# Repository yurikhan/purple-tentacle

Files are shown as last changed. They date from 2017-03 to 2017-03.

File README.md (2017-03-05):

# Purple Tentacle Keyboard

A DIY ergonomic mechanical computer keyboard.

## License

[][cc-by-sa4]

This work is licensed under a [Creative Commons Attribution-ShareAlike
4.0 International License][cc-by-sa4].

[badge]: https://i.creativecommons.org/l/by-sa/4.0/88x31.png
[cc-by-sa4]: http://creativecommons.org/licenses/by-sa/4.0/

The TMK Keyboard Firmware is licensed under GPL version 2 or later. Some
of its protocol files are under Modified BSD License.

Third party libraries used in the firmware have their own licenses.

## Documentation

For design documentation and build instructions, see the
[project site][site].

[site]: https://yurikhan.github.io/purple-tentacle/

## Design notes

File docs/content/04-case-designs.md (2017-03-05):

Title: Case designs
Date: 2017-01-27
Summary: The sandwich case.

## Overview

The case consists of four parts,
bottom to top:

<div markdown="1">
<figure>[][bottom]
<figcaption>[Bottom plate][bottom]</figcaption></figure>
<figure>[][spacer]
<figcaption>[Spacer][spacer]</figcaption></figure>
<figure>[][plate]
<figcaption>[Mounting plate][plate]</figcaption></figure>
<figure>[][frame]
<figcaption>[Top frame][frame]</figcaption></figure>
</div>

[bottom]: {filename}/images/04-case-designs/bottom.svg
[spacer]: {filename}/images/04-case-designs/spacer.svg
[plate]: {filename}/images/04-case-designs/plate.svg
[frame]: {filename}/images/04-case-designs/frame.svg

Seven M3 bolts with nuts
hold the parts together.

Palm supports are attached to the bottom plate
with M6 bolts and nuts.
The nuts are held in place
by the hexagonal cutouts in the spacer.

DXF files suitable for laser cutting
are available [from the project repository][dxfs].

[dxfs]: https://github.com/yurikhan/purple-tentacle/case/

## Source files

The remainder of this page
is only important
if you want to modify the physical layout.

This instruction assumes
you have the following software installed:

* LibreCAD

* Python 3

    * Additional packages
      listed in [`requirements.txt`][req].
      You should be able to install them with:

            $ pip3 install --user --requirement requirements.txt

* GNU Make

The preferred source for the case design
is the `master.dxf` file.
It uses blocks to make the design more flexible
and layers to separate case details.

After you modify the master drawing,
run `make all` in the `case` directory.
This will update the individual part DXFs
and images for this instruction.

[req]: https://github.com/yurikhan/purple-tentacle/tools/requirements.txt

## Table of Contents

[TOC]

### Layers

#### 0

The default layer.
Inserts of blocks go here.

#### Bottom, Spacer, Plate, and Frame

Contours that are unique to the named part.

#### Case upper

Contours common to the mounting plate and frame.

#### Case lower

Contours common to the bottom plate and spacer.

#### Case

Common contours of all details.

#### Keycaps

Rectangles for each keycap,
to aid the construction of cutouts in the top frame.

#### Palm supports

Schematics of the palm supports,
to aid in placing the attachment holes.

#### Construction: *

Several layers with auxiliary construction lines
which explain how features are placed.

#### Labels

Sizes, distances, offsets, and rounding radii.

### Blocks

#### Keyswitch cutout

A cutout for one keyswitch.
Change this if you plan to build a Cherry MX-based board.

#### Key

A [keyswitch cutout](#keyswitch-cutout)
and a single 1-unit keycap (19×19 mm).

#### Frame Key

A frame cutout for a single 1-unit [key](#key).

#### Key 1.5

A [keyswitch cutout](#keyswitch-cutout)
and a 1.5-unit keycap,
for the thumb base keys.

#### Frame Key 1.5

A frame cutout for a single [1.5-unit key](#key-1.5).

#### Frame Fgroup

A frame cutout for a horizontal row of four keys.

#### Fgroup

Four [key](#key)s in a horizontal row,
with a [frame cutout](#frame-fgroup),
for function keys.

#### Fkeys

Three [Fgroup](#fgroup)s,
plus two single [key](#key)s on the sides
with corresponding [frame cutout](#frame-key)s.

#### Column

Four [key](#key)s in a vertical column,
grouped so that you could easily adjust column staggering
in the [Hand](#hand) block.

#### Columns

Eight [column](#column)s
arranged according to column stagger.

If you ever need to adjust the column staggering pattern,
this is the place to do it.
It will be mirrored symmetrically.

#### Diamond

Four [key](#key)s in a diamond shape,
for navigation clusters.

#### Thumb cluster

Three 1-unit [key](#key)s
and a single [1.5-unit key](#key-1.5)
with a frame cutout,
for thumb clusters.

#### Hand

Combines the [columns](#columns),
a navigation cluster [diamond](#diamond),
and a [thumb cluster](#thumb-cluster).

#### LED

A 3 mm hole for a single LED.

If you use an opaque material for the top frame,
move the hole from the *Plate* layer
to the *Case upper* layer.

#### LEDs

Three [LED](#led) blocks in a vertical column.

The default LED spacing
is one unit (19 mm).

#### Case screw

A hole for an M3 bolt through all layers.

#### Palm support

* *Palm supports* layer:
  A schematic of the palm support.
* *Bottom* layer:
  Two holes for M6 bolts,
  coinciding with the mounting holes
  on the palm support base.
* *Spacer* layer:
  Cutouts for two hexagonal M6 nuts.

#### Main drawing

Combines the major blocks into a whole:

* [Function key bar](#fkeys)
* Two symmetrical [hand](#hand) blocks,
  each rotated about the origin
  by half the split angle
* [LEDs](#leds)
* [Case screw](#case-screw) holes
* [Palm rest](#palm-rest) attachment holes

This is also where all the manually constructed contours go:

* Frame cutout for the main block
* Exterior boundary
* Spacer cutout

Unfortunately, it’s not easy to automate these.
If you change the matrix,
you will have to re-construct them.
Open a copy of the original drawing alongside
and follow the hints in the *Construction* layers.

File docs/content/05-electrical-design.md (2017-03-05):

Title: Electrical design
Date: 2017-02-26
Summary: The wiring scheme.

## Overview

For reading convenience,
the schematic diagram is presented in three parts,
one part for each half of the matrix
and one part showing controller connection.

<div markdown="1">
<figure>[][left]
<figcaption>[Left half][left]</figcaption></figure>
<figure>[][right]
<figcaption>[Right half][right]</figcaption></figure>
<figure>[][schematic]
<figcaption>[Controller connection][schematic]</figcaption></figure>
</div>

[left]: {filename}images/05-electrical-design/left.sch.svg
[right]: {filename}images/05-electrical-design/right.sch.svg
[schematic]: {filename}images/05-electrical-design/schematic.sch.svg

**Note** that the column wires of opposite halves connect,
while the row wires do not.

## Source

These schematics are drawn in KiCad EDA.
The source project is in the `schematic` subdirectory.

The images above
are exported using the <kbd><kbd>File</kbd> | <kbd>Plot</kbd></kbd> command,
SVG format,
color mode,
no border and title block,
<kbd>Plot Current Page</kbd> individually for each page.
Afterwards, the SVG images are cropped using Inkscape.
A `Makefile` is provided.

## Concept

The keyswitches are arranged in a matrix
with 12 semi-rows
by 8 columns.
This allows a maximum of 96 keys
using 20 I/O pins.
(The theoretical maximum for 20 pins is
10×10 = 100 keys,
but 12×8 is a bit nicer to work with.
19 pins are insufficient
because they only allow 10×9 = 90 keys.)

The correspondence between keys and matrix cells
is pretty straightforward.
Note that function keys use the innermost columns.
Also note that the navigation and thumb clusters
are wired in a pseudo-row labeled AZ,
with three bottommost keys
arbitrarily assigned to the three outer columns.

An anti-ghosting diode
is placed in series with each keyswitch.
(See the [Rollover, blocking and ghosting][ghosting] article
on the Deskthority wiki
for details.)

[ghosting]: https://deskthority.net/wiki/Rollover,_blocking_and_ghosting

Keyswitches are wired for *active-low* logic.
That is, in order to read a semi-row,
the firmware pulls the corresponding semi-row pin to the ground,
activates the controller’s internal pull-up resistors
to drive inactive columns high,
and senses which column pins went low
as a result of keys being held down.
Thus, diodes have to be directed
towards semi-row wires.

(Active-high logic
would require pulling inactive columns down,
and the Atmega32U4 does not have internal pull-down resistors.
Without pull-downs,
inactive columns would become indeterminate.)

The eight column wires are connected
to the eight pins on the top edge of the Arduino Micro.
The twelve semi-row wires are connected
to pins on the bottom edge.
This leaves three pins
for the status LEDs.

The `RXLED` (`PB0`) pin is left unused.
In experiments,
it wouldn’t keep its assigned state.

Each LED is connected to a PWM-enabled pin
so that the firmware could control their brightness.
(This ability is currently unused;
the firmware implements its own PWM.)

The `PC7` pin,
also known as pin 13 in Arduino Micro,
normally drives the on-board LED.
The controller bootloader blinks this LED
while it’s working.
Wiring an externally visible LED to this pin
makes it possible to observe this blinking
when plugging the keyboard in
before the actual firmware kicks in.

LEDs are wired for *active-high* logic.
That is, the firmware pulls the LED anode pin to +5 V,
allowing the current
to flow through the LED into the ground.
(This simplifies reasoning about the LED state
in the firmware.)

A current limiting resistor is wired
in series with each LED.
See the [Limiting resistors][resistors] section
in the Bill of Materials
for the resistor value calculation formula.

[resistors]: {filename}03-materials.md#limiting-resistors

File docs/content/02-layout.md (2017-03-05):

Title: Layout
Date: 2016-12-10T14:00Z
Summary: Column-staggered, fixed split tenkeyless layout with thumb arcs.

Here is the physical layout of Purple Tentacle,
with various key groups highlighted.
The default keymap is shown;
you will be able to customize it.

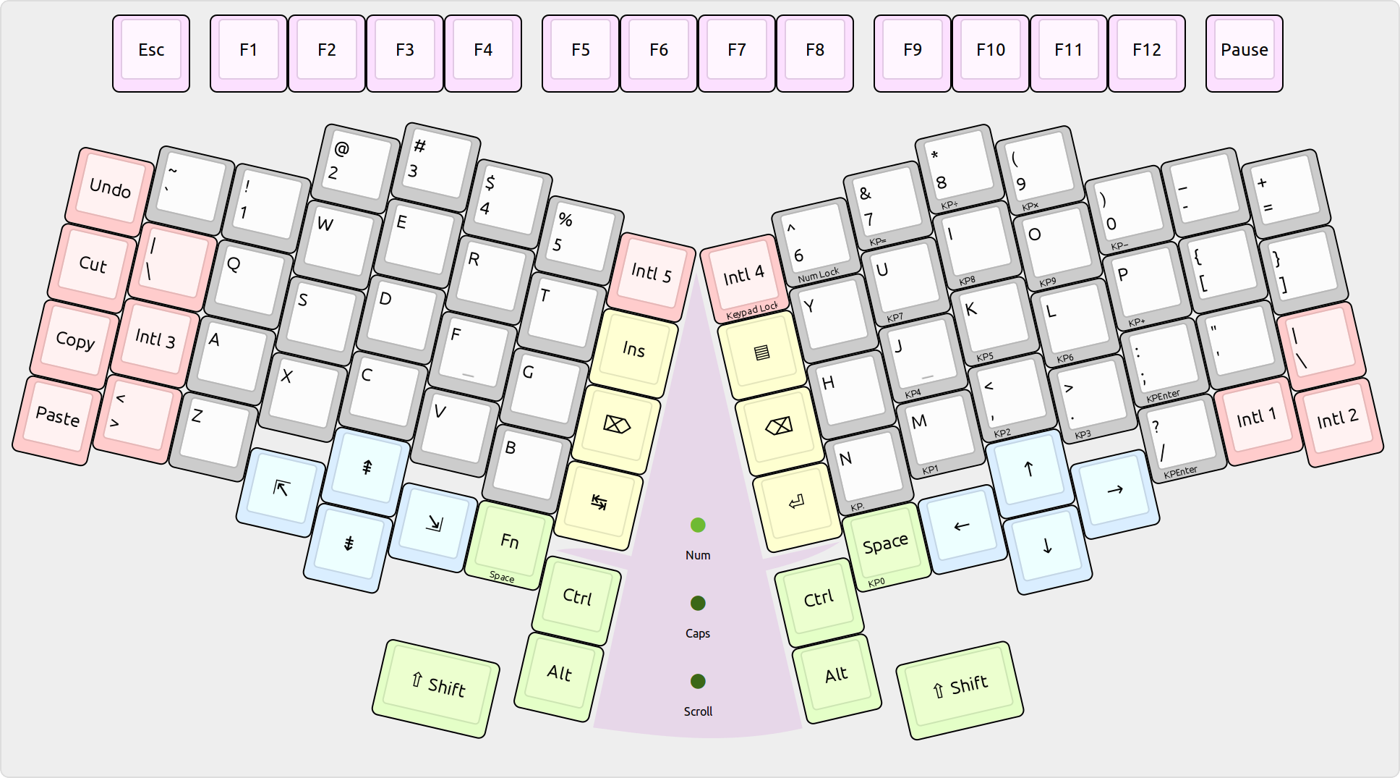
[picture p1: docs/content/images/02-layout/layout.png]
[][source]

[source]: http://www.keyboard-layout-editor.com/#/gists/0eb51054919d0ed51396cbd71c97c7d0

(Forking note:
the Corresponding Source for this image
is available [online][source].)

The main area is split into two halves,
with a fixed 26° angle between them.
(This provides the ergonomic advantages
of a split keyboard
while keeping the case design simple.)

Keys in the main area are arranged in straight columns,
which are staggered in accordance with finger lengths.

There are eight columns in each half;
the home position spans four columns in the middle.
Two additional outside columns are provided for the pinky,
and two inside columns for the index finger.
(This is in contrast
to the conventional non-split layout,
which has only two inside columns,
one outside column on the left
and three to four outside columns on the right,
overworking the right pinky.)

The default keymap
moves the most frequently used editing keys —
<kbd>Backspace</kbd>,
<kbd>Enter</kbd>,
<kbd>Tab</kbd>,
and <kbd>Delete</kbd>
(highlighted in yellow) — to the inside columns,
and duplicates one punctuation key
(US <kbd>\|</kbd>, or UK <kbd>#~</kbd>)
on the left hand.

This leaves several spare keys for user experimentation
(highlighted in red).
The default keymap assigns them
in a way that tries to accommodate most national layouts
out of the box.
However, if you create a keymap
that is substantially better
for a particular language,
please [send a pull request][pull]!

[pull]: https://github.com/yurikhan/purple-tentacle/pulls

Apart for the main area,
the layout includes:

* Function keys on the top,
  in groups of four
  (highlighted in purple).
  This grouping aids in finding them by touch.
* Two diamond-shape navigation clusters,
  positioned in the index–middle–ring finger columns
  and accessible without moving the wrist
  (highlighted in blue).
* Three keys for each thumb
  and two keys to be pressed with the base of the thumbs
  (highlighted in green).
  Arranging modifiers as shown above
  makes it possible to press two modifiers
  simultaneously with one thumb
  while leaving the other fingers in their home position.

The triangular shape in the middle,
highlighted in purple,
with the green status LEDs,
resembles a character from Day of the Tentacle,
a 1993 video game.
This is what the keyboard is named after.
(@Lucasfilm:
If you feel this infringes your trademark,
please [file an issue][issues].)

[issues]: https://github.com/yurikhan/purple-tentacle/issues

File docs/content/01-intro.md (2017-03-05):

Title: Introduction
Date: 2016-12-10T09:33Z
Summary: Purple Tentacle is a simple ergonomic desktop computer keyboard.

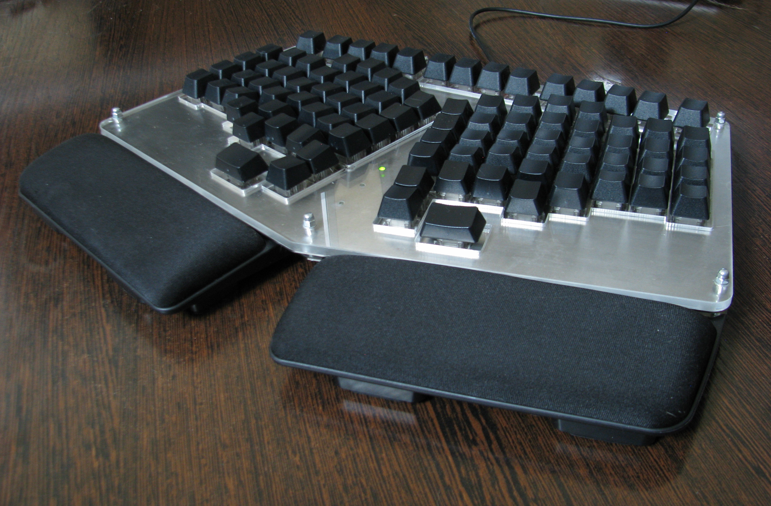
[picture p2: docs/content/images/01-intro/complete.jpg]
[][photo]

[photo]: {filename}/images/01-intro/complete.jpg

In a nutshell, Purple Tentacle is a
DIY
flat
one-piece
fixed split
ergonomic
mechanical
computer keyboard
for use with a desktop computer.

It pursues two goals:

* **Be simple to design and build.**
  You need to
  have access to a laser cutting facility
  and be able to solder,
  but that is pretty much it.

* **Be reasonably comfortable to use.**
  The computer keyboard as we know it today
  has evolved from a typewriter keyboard.
  Features were added
  while preserving backward compatibility.
  Some of the constraints underlying the designs
  are no longer relevant.

Minimalism is explicitly *not* a goal.
This is a desktop computer keyboard.
It’s not sacrificing functionality
in an attempt to make it easier
to carry around with you all the time.

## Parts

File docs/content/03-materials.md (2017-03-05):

Title: Bill of materials
Date: 2016-12-10T16:00Z
Summary: Parts you need in order to build a Purple Tentacle.

Here is the list
of parts and materials comprising a Purple Tentacle.
All costs are approximate.
Shipping is not included
as it will vary according to your location.

Proprietary parts are marked with a © symbol.
They are designed and produced
by the [Matias Corporation][matias].
In Europe, check [The Keyboard Company][keyboardco].

[matias]: http://matias.ca/
[keyboardco]: http://www.keyboardco.com/

|Part |Qty|©|Cost≈  |
|---|--:|-|---:|
|[Key switch](#key-switches) | 94|©|[^1]$25|
|[Keycaps](#keycaps) | 94|©|[^2]$50|
|[Palm supports](#palm-supports) (optional)|  1|©| $50|
|[Controller board](#controller-board) |  1| | $20|
|[USB cable](#cable) |  1| | $5|
|[Anti-ghosting diode](#diodes) | 94| | $1|
|[Status LED](#status-leds) |  3| | $1|
|[Limiting resistor](#limiting-resistors)  |  3| | $1|
|[Mounting plate](#mounting-plate) |  1| | $9|
|[Bottom plate](#bottom-plate) |  1| | $6|
|[Spacer](#spacer) |  1| | $15|
|[Top frame](#top-frame) (optional) |  1| | $10|
|[Wire](#wire) |12 m| | $1|
|[M3×… bolt](#m3-bolts-and-nuts) |  7| | $1|
|[M3 washer](#m3-bolts-and-nuts) | 14| | $1|
|[M3 acorn nut](#m3-bolts-and-nuts) |  7| | $1|
|[M6×10 bolt](#m6-bolts-and-nuts) |  4| | $1|
|[M6 washer](#m6-bolts-and-nuts) |  4| | $1|
|[M6 hexagonal nut](#m6-bolts-and-nuts) |  4| | $1|
|[Self-adhesive rubber feet](#rubber-feet) |2–5| | $7|
|**Subtotal (no palm supports)** | | |**≈$150**|
|**Subtotal** | | |**≈$200**|

## Key switches

Purple Tentacle is designed around Matias key switches.
A Cherry MX-based variant is possible
but many adjustments will be required
(different cutout size,
different plate thickness,
possibly different frame thickness).

Matias switches come in three variants:

* Quiet Click (PG155B01 or KS101Q)
* Click (PG155B02 or KS101)
* Quiet Linear (KS102Q)

They are sold in boxes of 200,
at $50 a box.

[^1]: Assuming you build two units,
    or split a box with a friend.

If unsure, choose Quiet Click.

## Keycaps

Matias keycaps are available in black or white;
blank or labeled.
They are made of ABS plastic,
have matte cylindrical surface,
and differ by row.

When choosing,
keep in mind the following considerations:

* The blank sets offered by the Matias Corporation directly
  have more keycaps than any of the labeled sets.
* The blank sets sold by The Keyboard Company,
  on the other hand,
  might not.
  Read the description carefully.
* Labeled sets are tailored
  to the conventional keyboard layout.
  You will be able to put *a* cap on each key,
  but not all labels will make sense.
  For example,
  no set offers a single-unit <kbd>Enter</kbd> keycap.

[Signature Plastics][sp] offers a limited selection
of keycaps with Alps mounts;
these are blank only,
more expensive,
and in various colors and profiles.

[sp]: http://pimpmykeyboard.com/

There is no default for the keycaps;
you have to make this choice.

[^2]: Assuming a Matias keycap set,
    with no Signature Plastics additions.

## Palm supports

Purple Tentacle uses palm supports
designed for the Matias Ergo Pro keyboard.
These come in five colors:
White, Black, Red, Navy Blue, and Astronaut Blue.
They are gel pads covered with silk,
attached to a plastic/steel base.

Whether to use palm supports
is a personal choice,
dependent on your typing habits.

If you do use the palm supports,
they will accumulate lint from your palms.
Once in a while,
detach them
and hand-wash with soap.
Do not put in a washing machine!
Dishwasher compatibility not tested.

## Controller board

For the controller,
choose an Atmel ATmega32u4-based breakout board
which exposes at least 23 I/O pins,
is wired for 5 V,
and is sufficiently small (≈50×20 mm or so).
Possibilities include
(but are not necessarily limited to):

* [Arduino Micro][arduino] or clone
* [Adafruit Atmega32u4 Breakout Board][adafruit]
* [Pololu A-Star 32U4 Mini][astar]
* [PJRC Teensy 2.0][teensy]

[arduino]: https://www.arduino.cc/en/Main/arduinoBoardMicro
[adafruit]: https://www.adafruit.com/products/296
[astar]: https://www.pololu.com/product/3102
[teensy]: https://www.pjrc.com/teensy/index.html

These boards do *not* expose enough pins:

* Pololu A-Star 32U4 Micro (18 pins)
* SparkFun Pro Micro (18 pins)

This instruction assumes Arduino Micro.
For other boards,
minor adjustments to wiring
and/or firmware may be needed.

Note that some boards
will not advertise their total pin number.
For example,
Arduino Micro advertises 20.
For best results,
check the schematic
and count I/O pins
which have no other components attached.

If the board has a pin
that only drives a general-purpose LED,
count it also;
use it for one of the keyboard status LEDs.
(This way you get useful feedback
when the bootloader flashes this LED.)
Avoid pins that drive fixed-purpose LEDs
such as RXLED and TXLED.

Given a choice, prefer boards
that come *without* solderless breadboard pins attached —
they won’t fit in the keyboard case
and you’ll have to desolder them.

## Cable

Choose a cable so
that one end fits the controller board
(either mini or micro USB B male connector)
and the other end has a standard USB A male connector.
Choose a length that fits your working environment.
Avoid ferrite rings
and L-shaped connectors
as they will be a hassle to fit in the keyboard case.

## Diodes

To prevent ghosting,
a diode is installed
in series with each key switch.

This instruction assumes 1N4148 diodes.

## Status LEDs

For status indicators
(Num Lock, Caps Lock, Scroll Lock),
choose LEDs that will
fit in 8 mm space
and have forward voltage of 3 V or less.
Prefer diffused ones.
Choose through-hole mount,
not surface mount.

This instruction assumes ⌀3 mm green LEDs,
forward voltage 1.8–2 V,
maximum current 20 mA.

## Limiting resistors

Calculate the minimum limiting resistor value as
<var>R</var><sub>min</sub> =
(<var>V</var><sub>cc</sub>
− <var>V</var><sub>f</sub>)
/ <var>I</var><sub>max</sub>,
where
<var>V</var><sub>cc</sub> = 5 V,
<var>V</var><sub>f</sub> is the LED forward voltage,
and <var>I</var><sub>max</sub> is the LED maximum current,
and use an actual value above that
in order to keep the current through LEDs within specifications.

For best results,
try resistors of several values
and choose the one that yields the most comfortable LED brightness.
Your goal is to make the LED noticeable
but not painful to look at.
Be sure to test
both in bright daylight
and in dim lighting.

For example,
for the LEDs specified above
the formula gives a minimum resistance of 150 Ω,
but a 1 kΩ value gives a more pleasant brightness.

## Mounting plate

Matias switches are mounted on a plate 1 mm thick.
Ask your laser cutting facility
what materials they carry.

If in doubt,
choose stainless steel.
(If you make a Purple Tentacle
with a plate made of a different material,
please [share your experience][materials]!)

[materials]: https://github.com/yurikhan/purple-tentacle/issues/1

## Bottom plate

The bottom plate covers the electronics from below.
If you choose to use palm supports,
the bottom plate is what they attach to.

This instruction assumes 1 mm stainless steel,
same as the mounting plate.

## Spacer

The spacer is the layer of the case
between the bottom plate and the mounting plate.
It provides outer walls
for the internal cavity
that houses the electronics.

This layer must be at least 9 mm thick.
When key switches are inserted into the mounting plate,
their pin ends will go 8 mm below the plate level,
and you will need a little space
so that the bottom plate does not touch them.

Ask your laser cutter facility
what materials they carry
and what they work with.
If they don’t have anything suitable,
ask what size the raws need to be.

The choice is purely aesthetical.

With translucent plastics,
electronic components next to the edges
will be visible through the case walls.
Also, if your controller board
has an always-on power LED,
it will shine through the back.

This instruction assumes 10 mm clear acrylic.

## Top frame

The top frame provides walls around the keycaps.
It is optional if you do not have kids or pet cats.
If you do, a frame is highly recommended;
otherwise you may find
these can spuriously act
as poorly controlled keycap pullers.

The distance from the mounting plate
to the bottom edge of keycaps
is 8 mm.
On the other end,
experience shows
that a 10 mm frame
makes it difficult to press the thumb base keys.
Therefore, 8 mm thickness is recommended.

The choice of material is mostly aesthetical.
If it is opaque,
you will need holes for the status LEDs.

This instruction assumes 8 mm clear acrylic.

## Wire

Purple Tentacle does not use a PCB;
instead, it is hand-wired.
There are a couple of reasons for that:

* When building a single unit or two,
  manufacturing a board
  is more hassle than hand-wiring.
* Given that switches are inserted
  into the mounting plate
  from above,
  soldering them to a PCB below
  will make it almost impossible
  to replace a faulty switch
  without desoldering the whole board.
  Faulty switches *do* happen,
  and you will discover them
  only after finishing assembly
  and typing for a few hours.

Matrix rows are wired with diode pins;
for everything else you need wire.
If you have soldering experience,
use whichever wire is convenient for you.
(You probably already have a stash of soldering wire.)
If not, choose solid core copper wire,
around AWG 26 (0.13 mm<sup>2</sup>).

Category 5 twisted pair can be used
if that’s what you have handy.
It provides convenient color coding for the wires,
although it is a bit too rigid.
If you go this way,
you need 1.5 m 4-pair UTP
or 3 m 2-pair UTP.

## M3 bolts and nuts

M3 bolts and acorn nuts
screw the case details together.
Washers protect the top frame
against excessive pressure from the nuts.

Choose a bolt length
that is 2 to 4 mm longer
than the total thickness
of the bottom, spacer, plate, and frame (if used).
Add washers if needed.
(The M3 acorn nut has a depth of 4.5 mm.)

For example:
1 mm bottom
+ 10 mm spacer
+ 1 mm plate
+ 8 mm frame
= 20 mm.
The next standard screw length is 25 mm,
which is a bit too long.
The standard M3 washer is 0.5 mm
so we add two of them.

Choose a head shape with a flat underside,
not a countersunk one.

## M6 bolts and nuts

M6 bolts, washers and nuts
are used to attach palm supports.
If you don’t want palm supports,
you can skip these.

The palm supports provide an elevation of ≈8 mm
to the front edge of the keyboard.
This should accommodate most M6 bolt heads
so they won’t scratch your desk.

Choose a head shape with a flat underside,
not a countersunk one.

## Rubber feet

Rubber feet prevent the keyboard from moving on your desk.
Additionally,
they prevent the case bolt heads
from scratching the desk surface.

Choose feet thickness
so that it exceeds the bolt head height.
4 mm or higher
should accommodate most standard shapes of M3 bolt heads.

With palm supports,
two rubber feet are sufficient.
Without palm supports,
you might want five.

The best-known supplier is 3M.
Suitable feet are sometimes bundled
with network appliances such as
switches, home routers, and WiFi access points.

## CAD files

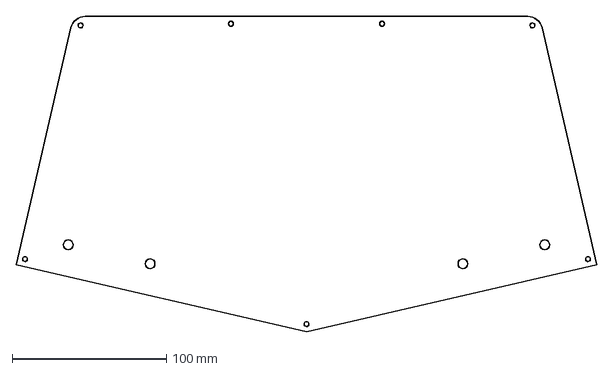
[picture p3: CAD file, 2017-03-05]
case/bottom.dxf
376.7 x 204.5 mm

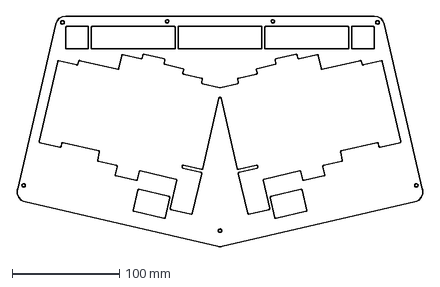
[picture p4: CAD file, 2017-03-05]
case/frame.dxf
379.3 x 214.6 mm

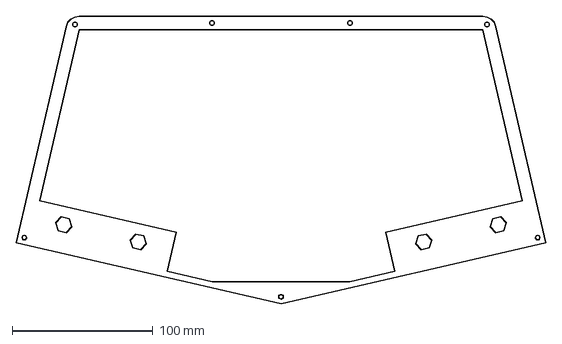
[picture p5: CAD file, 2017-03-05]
case/spacer.dxf
376.7 x 204.5 mm

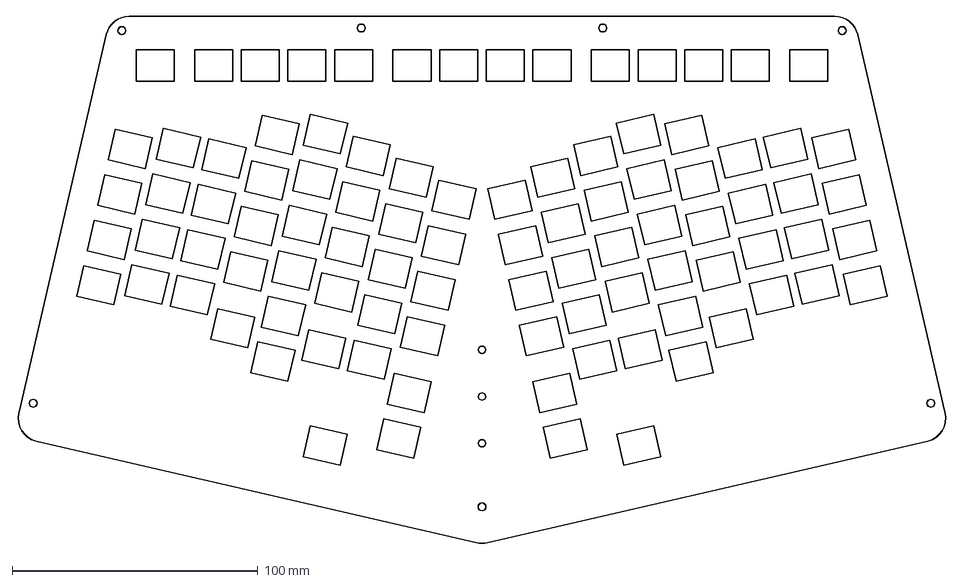
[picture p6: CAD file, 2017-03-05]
case/plate.dxf
379.3 x 214.6 mm

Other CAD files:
case/master.dxf

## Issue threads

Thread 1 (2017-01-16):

Materials

yurikhan, 2017-01-16:
The initial two builds of the Purple Tentacle used stainless steel for the plate and the bottom, and clear acrylic for the spacer and top frame.

If you build a Purple Tentacle with other materials, please share your experience:

* What materials did you use?
* How much did they cost?
* What advantages and disadvantages do they have?
* Are you happy with the result?

yurikhan, 2017-01-16:
I used stainless steel 1 mm for both the plate and the bottom, 10 mm clear acrylic for the spacer, and 5 mm clear acrylic for the frame. The laser cutter facility provided the steel, but I had to purchase acrylic separately. The four details cost me ≈40 USD, cutting included.

The resulting case is pretty heavy, weighing in at ≈2 kg. Steel details contribute ≈1 kg to that.

The 5 mm frame leaves a small gap between the top surface of the frame and the bottom edge of keycaps. When one of my two cats feels particularly naughty, he is able to pry keycaps off with his teeth. If he persists, I may have to swap the frame for a 8 mm one.

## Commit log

2017-03-05 Add documentation framework
2017-03-05 doc: Add bill of materials
2017-03-05 Add case
    [bottom.dxf, frame.dxf, master.dxf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]
2017-03-05 Add schematic
    [left.sch, right.sch, schematic.sch]
